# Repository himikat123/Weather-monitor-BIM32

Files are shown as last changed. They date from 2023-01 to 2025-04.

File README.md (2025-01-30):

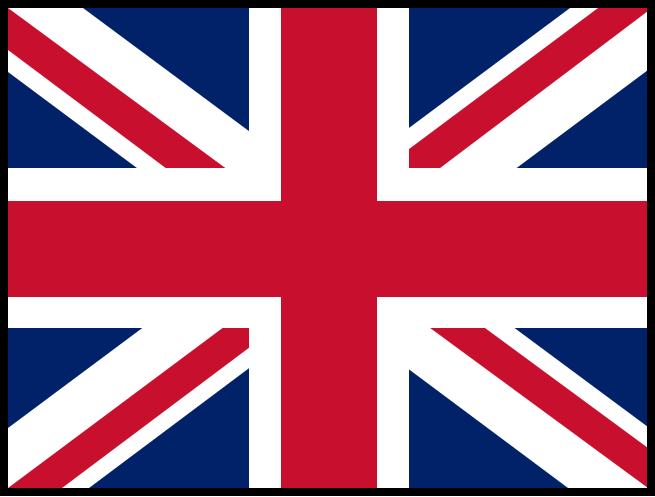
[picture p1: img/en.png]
Read this in english

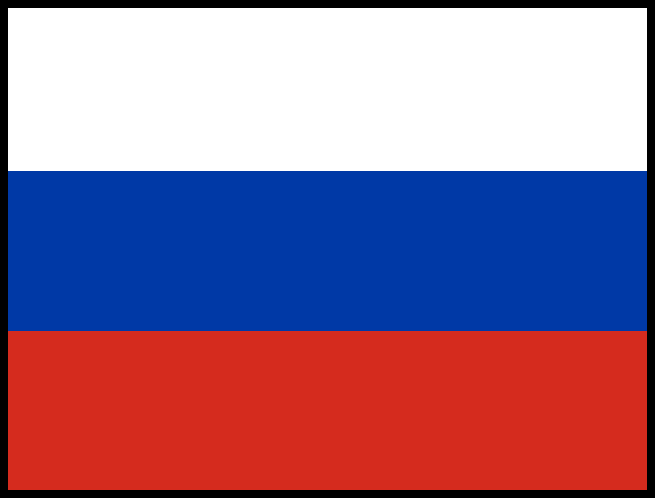
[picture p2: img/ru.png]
Читать на русском


# BIM32 weather monitor
## Weather monitor on ESP32

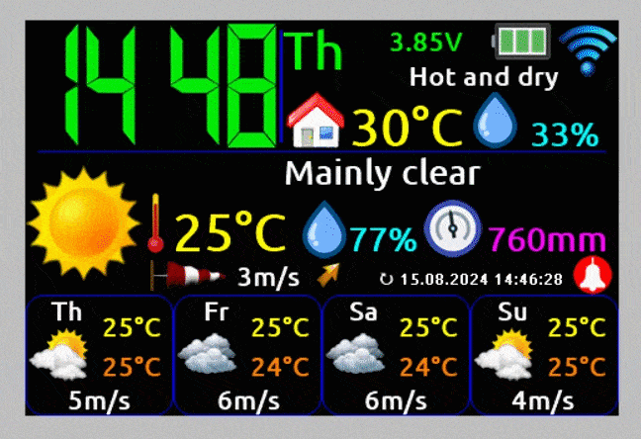
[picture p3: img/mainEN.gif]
Weather monitor based on ESP32


### Brief list of weather monitor features:

* Connect to home WiFi network 2.4 GHz
* Display current weather and weather forecast for 3 days
* Display hourly weather forecast for 5 days
* Display weather history (hourly) for 1 day ago
* Charts building (temperature, humidity, pressure and precipitation probability)
* Display Temperature, Humidity, CO2 and Index of Air Quality in the house
* Home weather control (Humidifier, Dehumidifier, Heater, Cooler and Purifier)
* Clock (Small/Large/With seconds/Analog) with NTP synchronization
* Calendar with the ability to scroll up to plus/minus infinity
* Sending and/or receiving data from/to thingspeak
* Sending data to narodmon
* Up to 2 wireless Temperature/Pressure/Humidity/CO2/ambient light/voltage/current/power/energy sensors
* Support wired Temperature/Pressure/Humidity/Index of Air Quality/Ambient light sensors
* Auto-adjust the brightness of the screen backlight (by ambient light sensor, by time or by the fact of sunrise and sunset)
* 3.5 or 3.2 inch color touch display
* Support 6 languages: English, German, Russian, Polish, Ukrainian, Bulgarian
* Optional 7-segment color display of large and even huge clocks
* Talking clock
* Alarm clock playing mp3 files
* Sound alert when Temperature, Humidity, CO2 and Air Quality go beyond comfort limits
* Very flexible settings via web interface

```diff 
- Attention to all who want to add support for the sensor or display you need. There are three ways to do this:
- 1. Do it yourself, the source code is freely available
- 2. Send me the sensor/display you need
- 3. Pay for adding the sensor/display you need
```

## Wiring diagram for base weather monitor modules
To start and operate the weather monitor, just connect **display** to **ESP32**. Connecting all other modules is optional.

Instead of schematic diagrams, I post half-drawings, half-photos, so that it is clear to beginners and even non-professionals. I ask professionals not to be upset, normal schematic diagrams will also be.

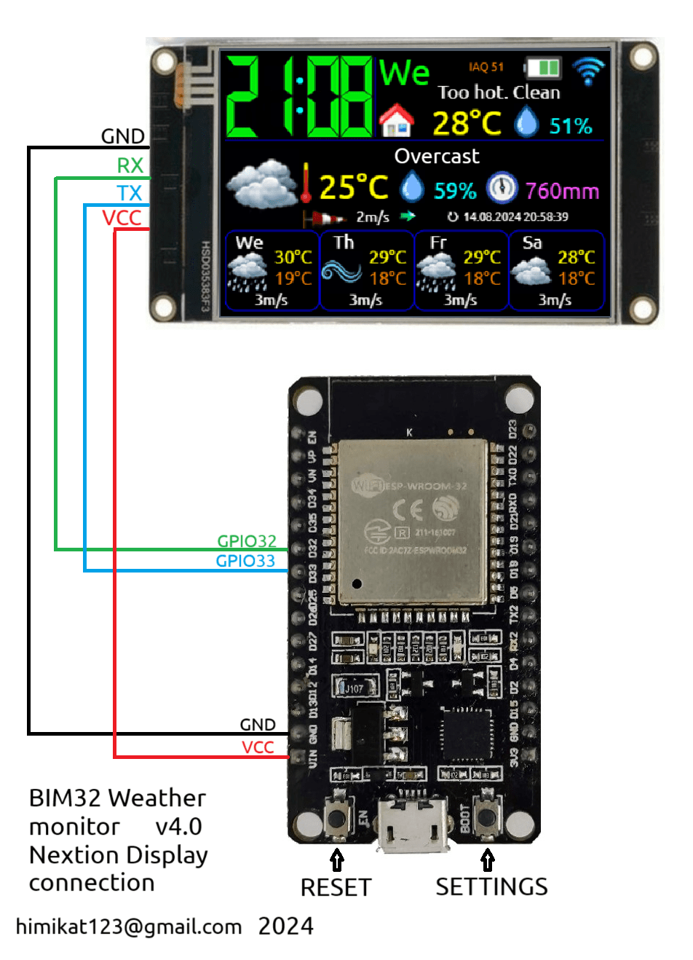
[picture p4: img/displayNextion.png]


You can use the extended version of the **Nextion** display **NX4832K035**, or the basic **NX4832T035**. In the case of the basic model, you will not have access to the clock with seconds, weather graphs, and alarm control from the screen.

Alternatively, you can use the ILI9341 display.

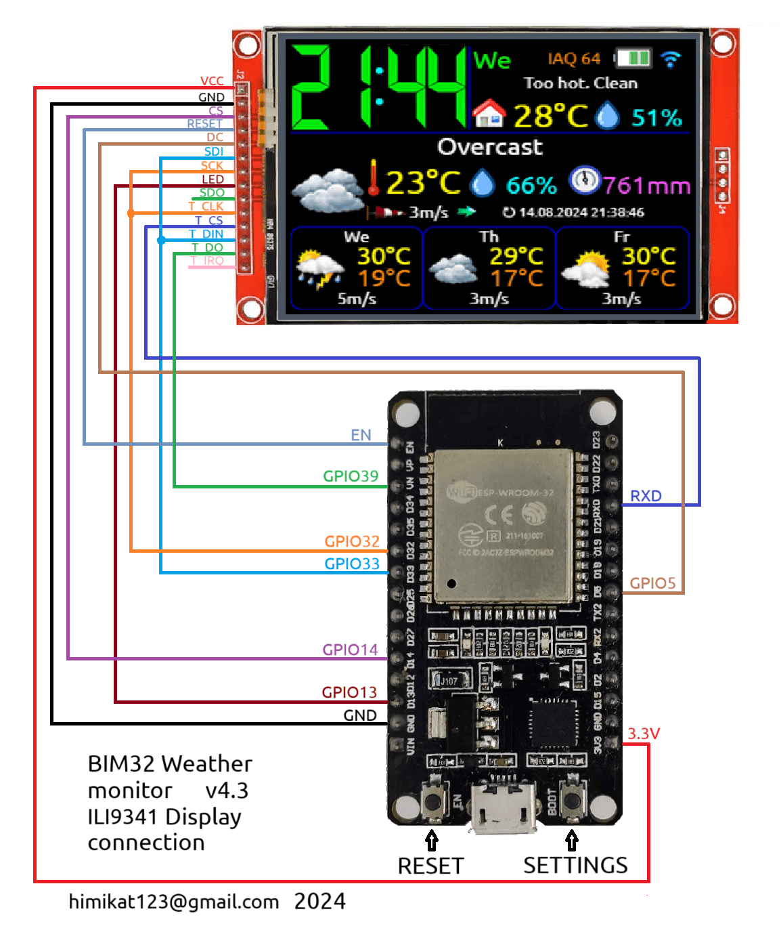
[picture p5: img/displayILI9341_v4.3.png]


If anyone need to have a display on/off button at hand, it can be connected according to the following scheme.

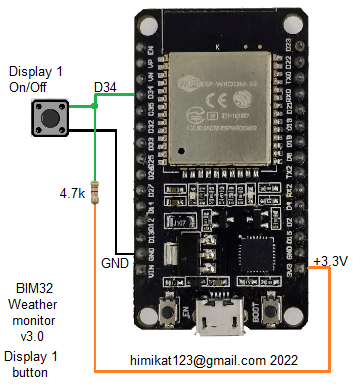
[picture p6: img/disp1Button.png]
weather monitor BIM32 display 1 button


## Wiring diagram of connecting wired sensors to the weather monitor
To the **weather monitor** can be connected wired sensors for temperature, humidity, pressure, index of air quality and ambient light. **The monitor** supports the following sensors:
* BME280
* BME680
* BMP180
* SHT21
* DHT22
* DS18B20
* MAX44009
* BH1750
* photoresistor

You can connect any one, several, or all sensors from this list at once. If your display is not **NX4832K035** it is recommended to install the DS3231 real time clock chip. The connection diagram is as follows.

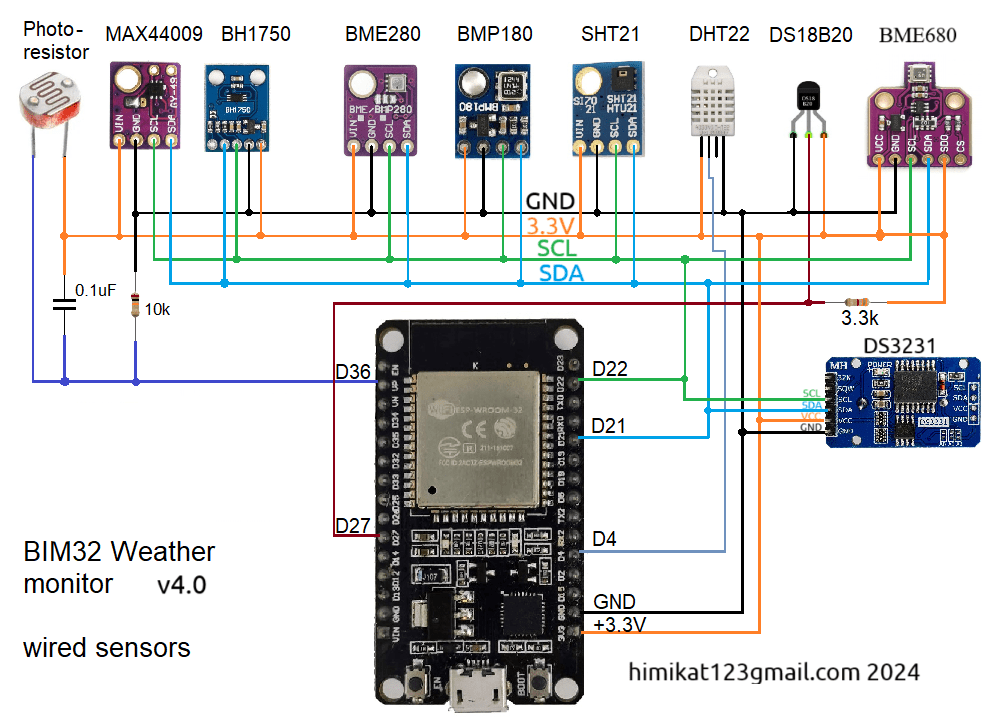
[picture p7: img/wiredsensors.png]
weather monitor BIM32 wired sensors


## Wiring diagram of the radio channel module for communication with wireless sensors
Also, **[wireless sensors](https://github.com/himikat123/Radio-sensor)** can be connected to the **weather monitor**, for this you need to add the radio channel module **HC-12** according to the diagram below.

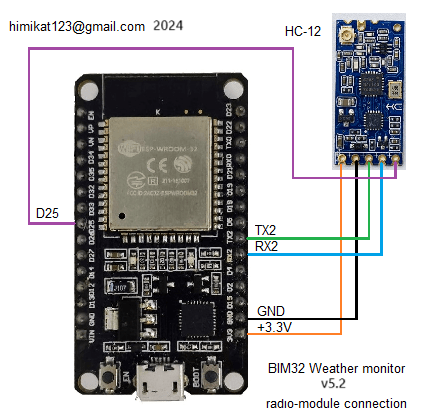
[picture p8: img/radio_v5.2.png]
weather monitor BIM32 radio channel


## Wiring diagram for weather control devices in the house
To control the weather in the house, you can connect a humidifier and dehumidifier, as well as a heater, cooler (fan or air conditioner) and air purifier. I cannot provide a connection diagram for these devices, since everything depends on how the control is implemented in each specific device (remote control, buttons, voltage). Therefore, I will simply indicate on which pins of **PCF8574** logical signals will appear when need to turn on this or that device.

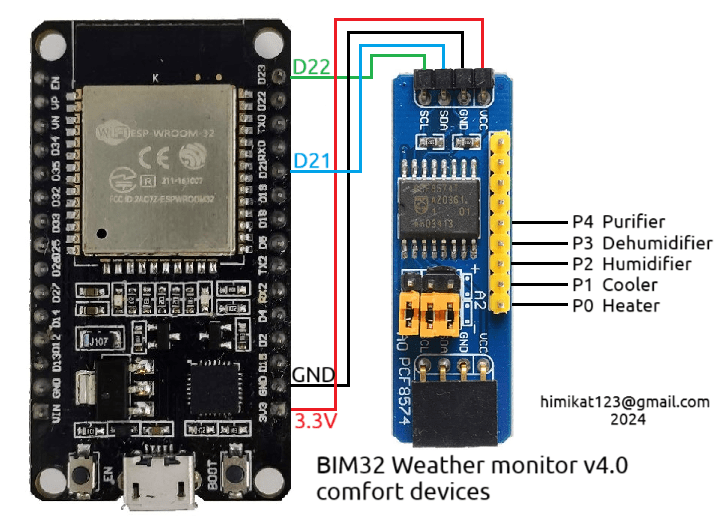
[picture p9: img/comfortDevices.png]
weather monitor BIM32 humidifier dehumidifier heater cooler


## Sound module connection diagram
To enable the alarm clock and the talking clock to produce sounds, the **DF-Player mini** mp3 player module is used, the connection diagram for which is shown below. You will need to copy the entire contents of the **SDcard** folder to the **micro-sd card**, having previously formatted it in the FAT32 file system. If you do not need sound, just connect the GPIO18 ESP32 pin to ground.

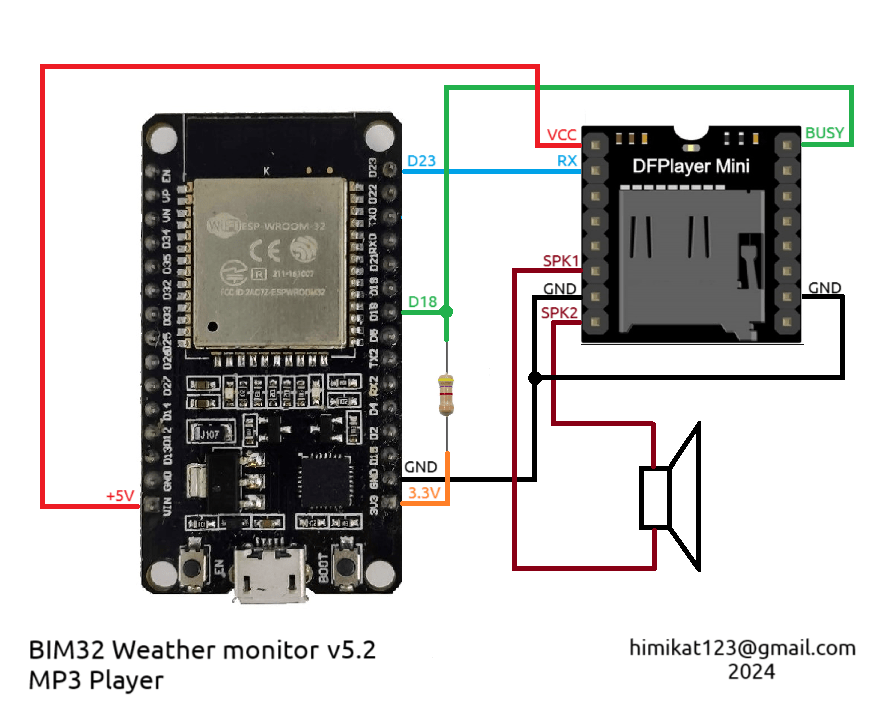
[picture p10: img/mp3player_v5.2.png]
weather monitor BIM32 MP3-player


Having used this device, an unpleasant moment was discovered: this mp3 player module produces a constant low noise. To get rid of the noise, you need to re-solder the resistor from position A to position B, shown in the photo below. This manipulation switches the MUTE input of the amplifier to the BUSY output, on which a log. signal appears only during sound playback.

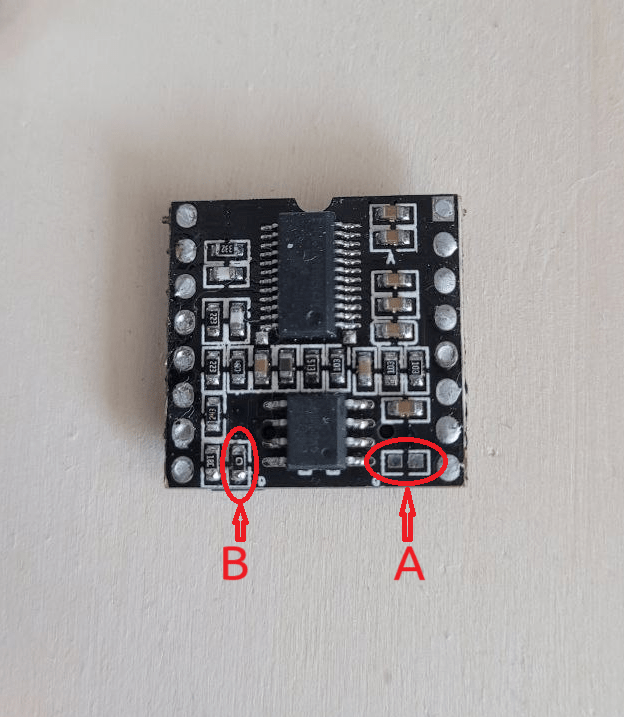
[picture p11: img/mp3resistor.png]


## Weather monitor circuit

Well, as promised, a normal general schematic diagramm for general development. 

```diff 
- Please note if you choose not to install buttons 
- (turn on/off displays and turn off alarms), 
- the pull-up resistors of these buttons still need to be installed.
```

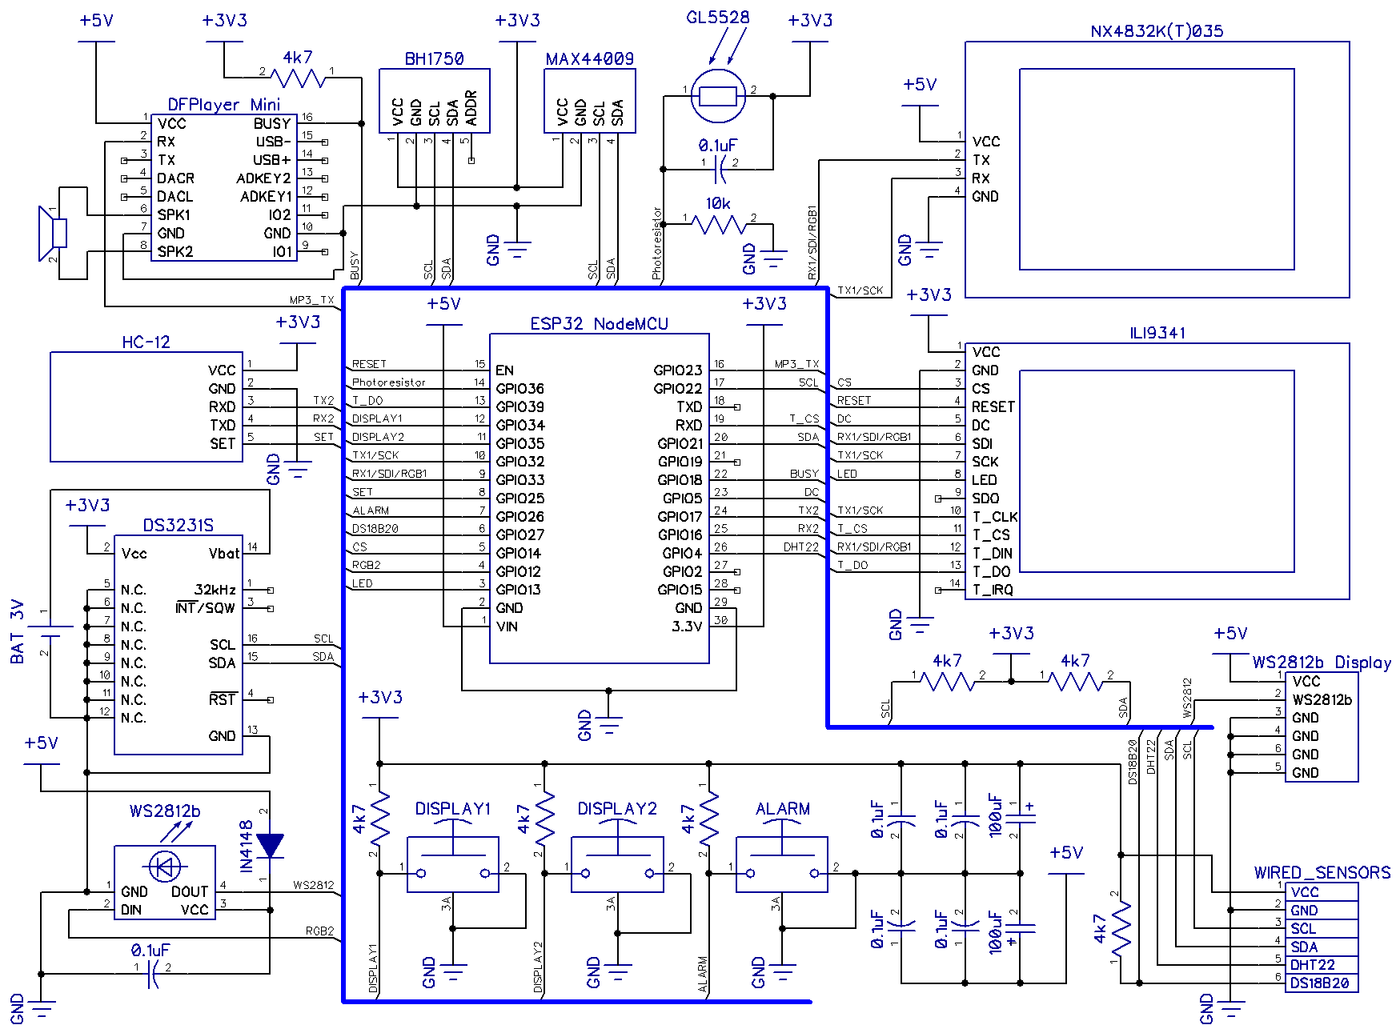
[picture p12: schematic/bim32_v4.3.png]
weather monitor BIM32 schematic diagramm


## Weather monitor flashing
To flash the weather monitor, you will need a **micro-sd** card, a **micro-USB** cable and a computer.

To flash the **Nextion display**, you need to copy the display firmware file (a file with the model name of your display .tft) from the **bin** folder to the **micro-sd** card (the card must be formatted in the **FAT32** file system). Then insert the flash drive into the **micro-sd** slot of the display and supply it with power. The display will flash itself from the flash drive, the flashing progress will be displayed on the screen.

To flash **ESP32**:
1. Download [flash_download_tools](https://www.google.ru/search?q=flash_download_tools)
2. Run it, select ESP32 DownloadTool
3. Select the firmware binaries (located in the bin folder) and the addresses as in the screenshot. And the COM port number
4. Press the Start button in the flashing program and the Settings button on the device (the BOOT button on the ESP32 module). Keep the Settings button pressed until the flashing process starts.

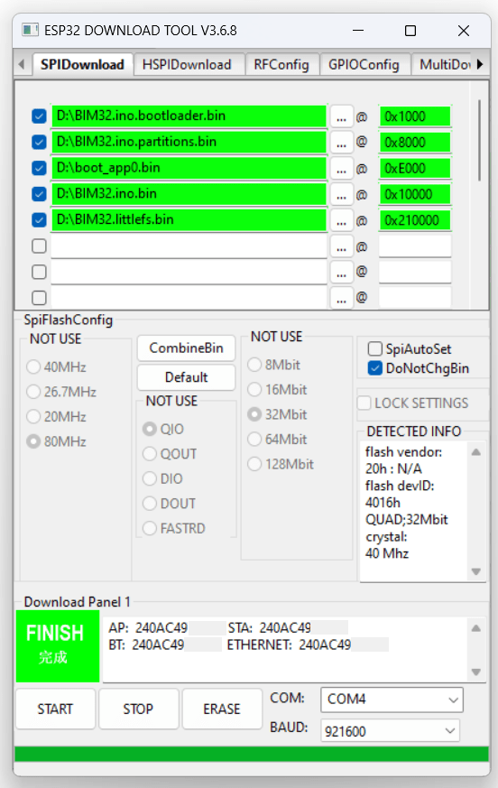
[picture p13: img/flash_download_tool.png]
weather monitor BIM32 flashing


After the flashing **the weather monitor** needs to be configured. An unconfigured device turns on the access point (creates a WiFi network) **BIM32** with the default network password **1234567890**. And in the future, to turn it on again, you need to press and hold the **Settings** button until the access point symbol appears on the screen instead of the antenna symbol. After connecting a laptop or smartphone to the **BIM32** network, open a browser and navigate to **http://192.168.4.1**. Enter login **admin** and password **1111** to open the settings page. In the future, for security reasons, it is recommended to change the default login and password.

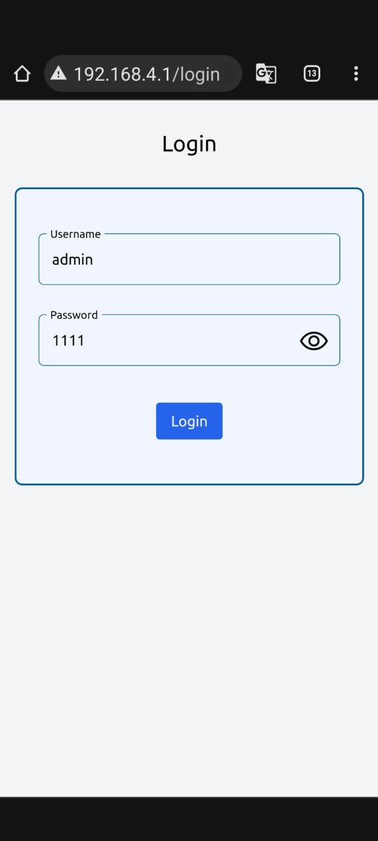
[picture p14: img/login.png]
weather monitor BIM32 login


Also, when the device is already configured and connected to the network, you can get into the settings without pressing the **Settings** button, just enter the IP address of the **weather monitor** in the browser. You can find out this address by tapping on the antenna symbol on the screen of the **weather monitor**.

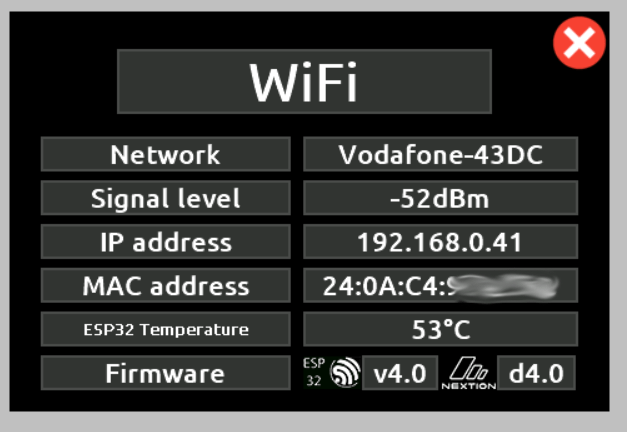
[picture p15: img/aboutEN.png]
weather monitor BIM32 about
<hr />

## A demo of the settings page can be viewed <a href="https://himikat123.github.io/Web-Interface-BIM/" target="_blank">here</a>

## Photos of the weather monitor
Well, and finally traditionally a few photos of the resulting device. The case is printed on a 3D printer, you will find the files for 3D printing in the **enclosure/STL/** folder.

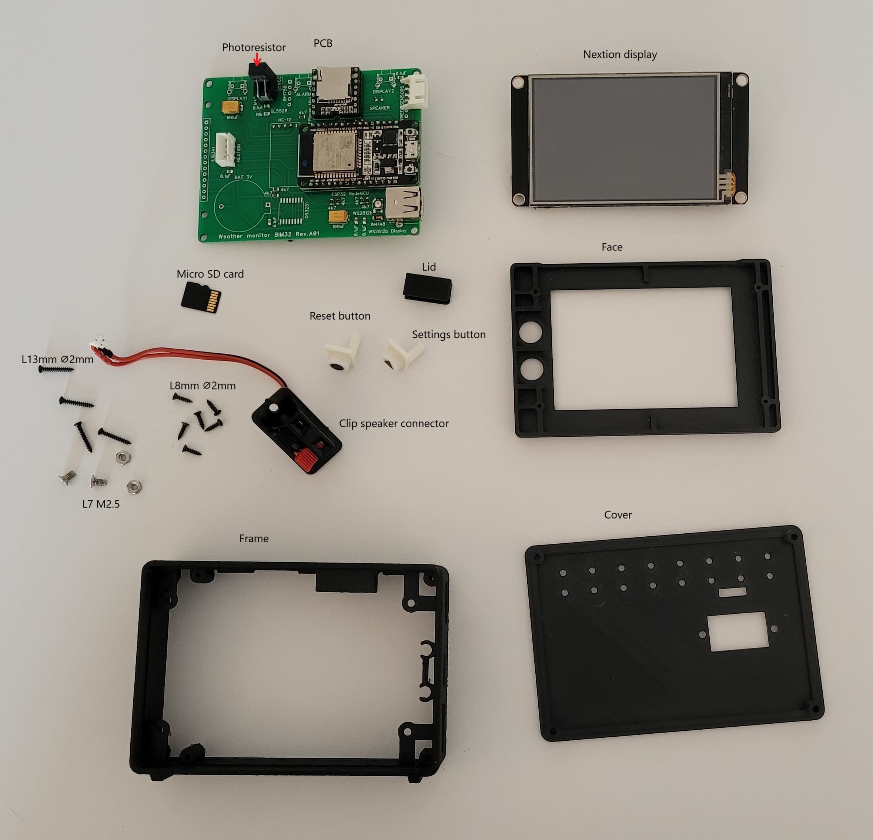
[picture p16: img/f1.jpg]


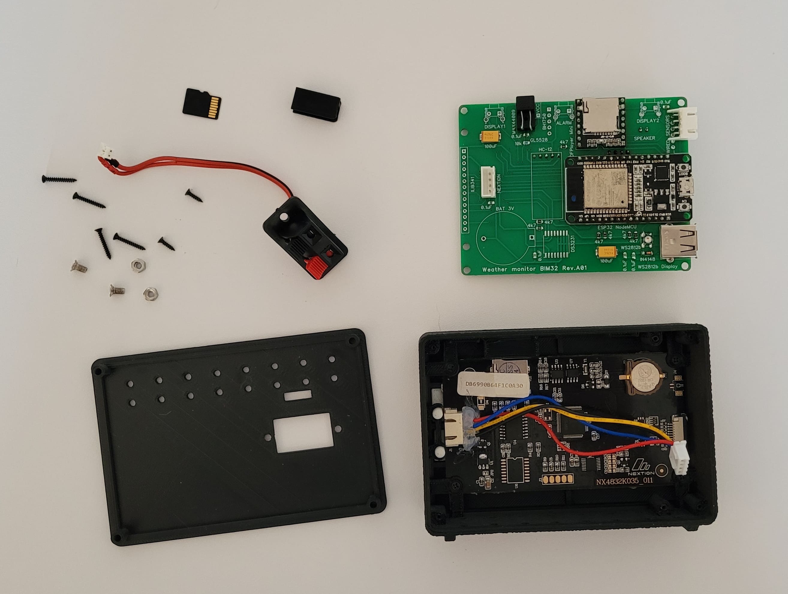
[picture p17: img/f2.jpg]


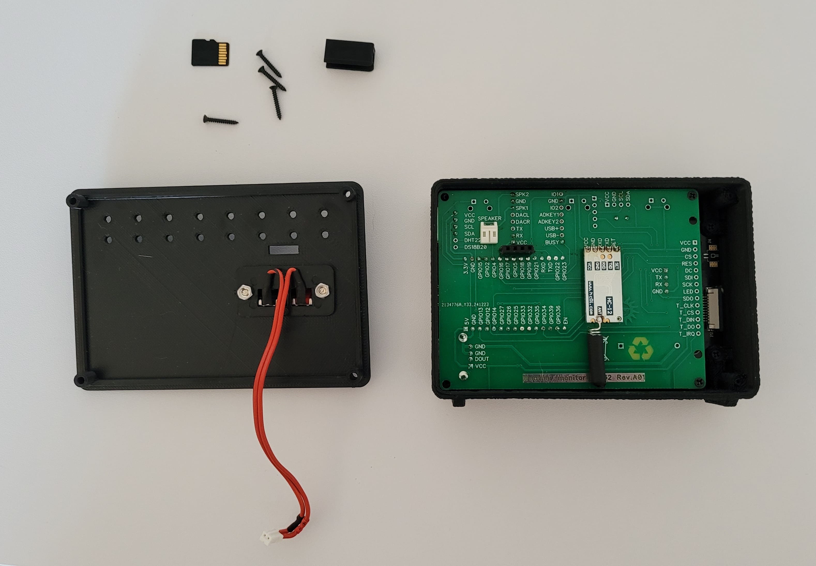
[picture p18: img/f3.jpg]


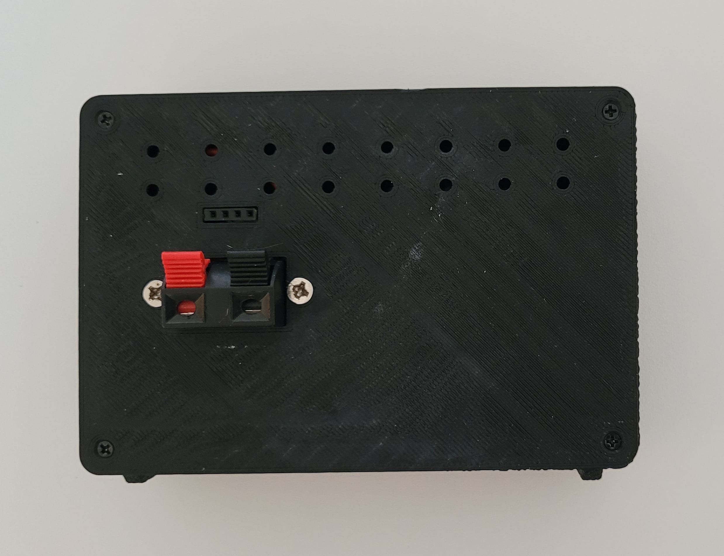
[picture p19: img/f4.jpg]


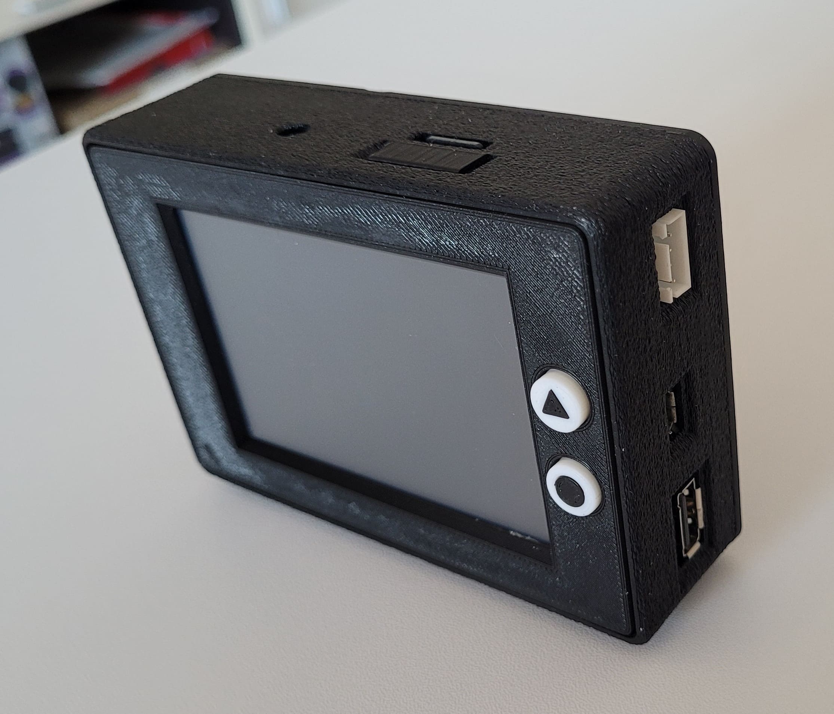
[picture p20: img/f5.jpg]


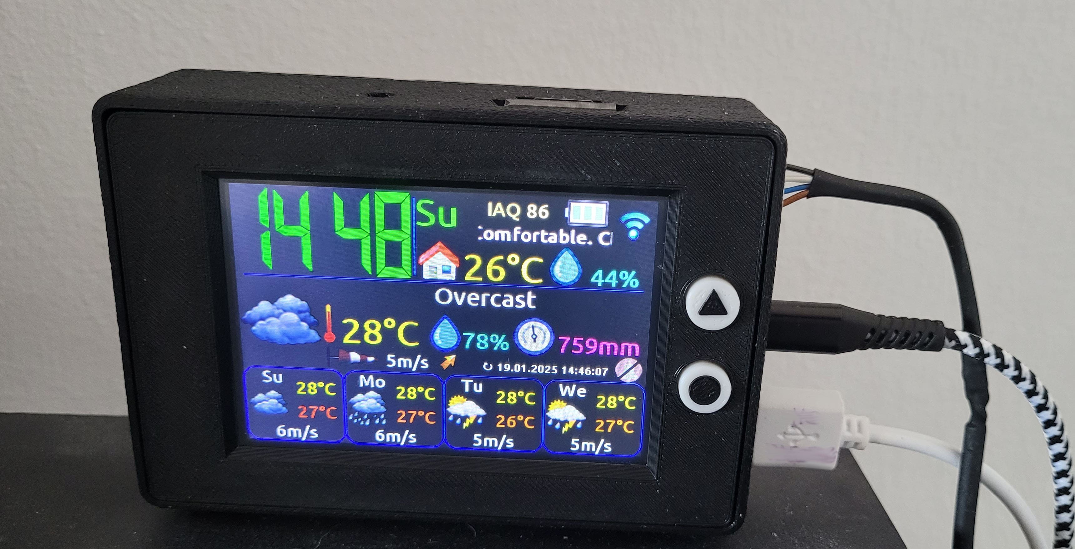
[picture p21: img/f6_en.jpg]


<hr>

## Do you like the project? Buy me coffee or beer.

<a href="https://www.buymeacoffee.com/himikat123Q">
    Donate
</a>

<a href="https://www.paypal.com/donate/?hosted_button_id=R4QDCRKTC9QA6">
    
</a>

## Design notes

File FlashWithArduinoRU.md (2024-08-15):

1. Добавляем в **Arduino IDE** поддержку **ESP32**, находим [инструкцию](https://www.google.ru/search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)
2. Добавляем в **Ардуино** плагин для заливки **SPIFFS** находим [инструкцию](https://www.google.ru/search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)
3. Распаковываем библиотеки из файла **libraries.zip** в папку `C:/Users/Username/Documents/Arduino/libraries`
4. Открываем файл `C:/Users/Username/AppData/Local/Arduino15/packages/esp32/hardware/esp32/1.0.5/platform.txt` и находим (поиском) строчку
`compiler.elf2hex.extra_flags=`, добавьте новую строку: `compiler.libraries.ldflags=`

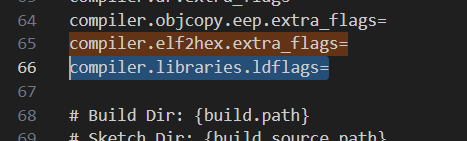
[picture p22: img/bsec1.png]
BSEC flags


Потом, в этом же файле, находим `{compiler.c.elf.libs}` и добавляем за ним, в ту же строку: `{compiler.libraries.ldflags}`

BSEC ldflags

5. Прошиваем плату скетчем
6. Прошиваем файлы файловой системы **SPIFFS**, в Ардуино нужно выбрать **Инструмены --> ESP32 Sketch Data Upload**

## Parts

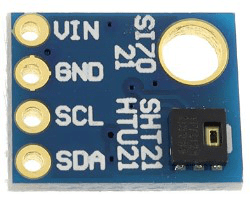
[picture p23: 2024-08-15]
img/components/sht21.png

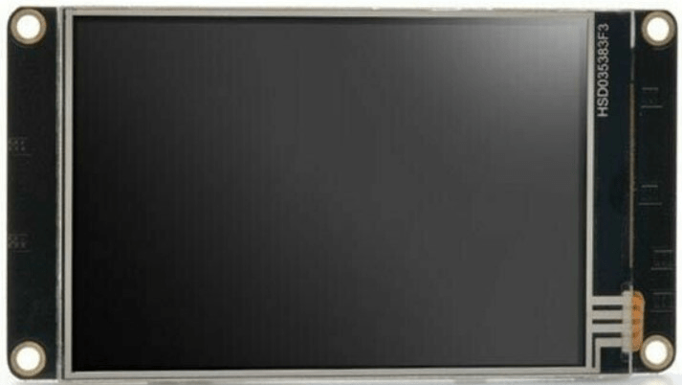
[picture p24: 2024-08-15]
img/components/nextion.png

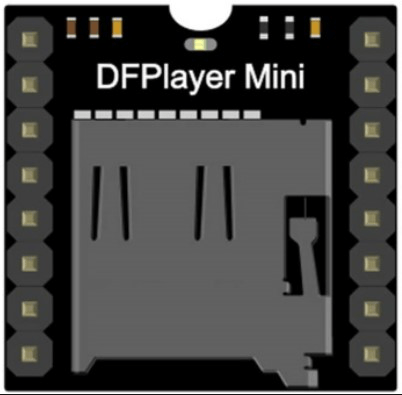
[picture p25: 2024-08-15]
img/components/df-player mini.png

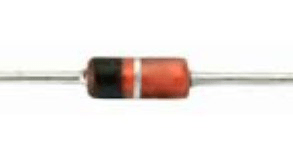
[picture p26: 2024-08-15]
img/components/1n4148.png

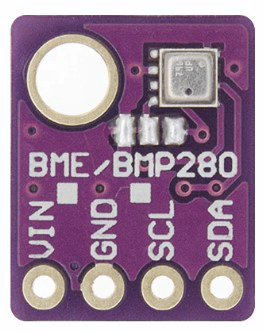
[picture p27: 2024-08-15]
img/components/bme280.png

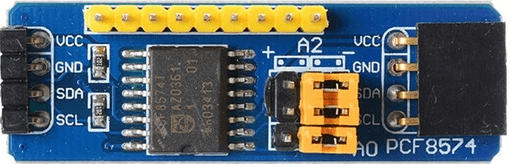
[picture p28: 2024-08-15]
img/components/pcf8574.png

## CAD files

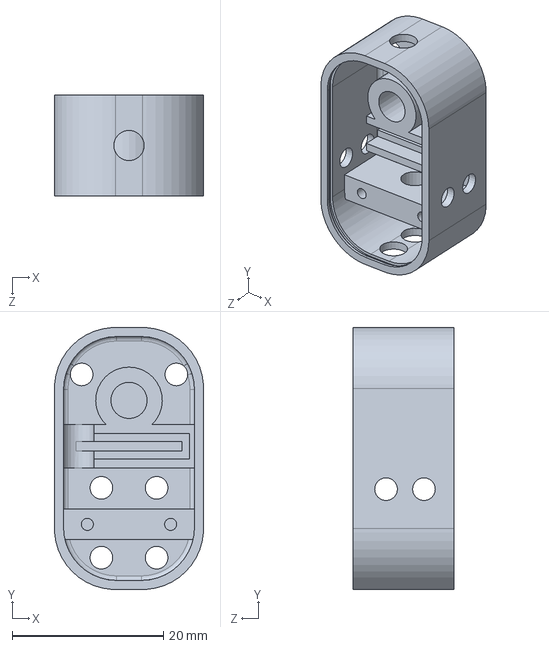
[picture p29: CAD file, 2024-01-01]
enclosure/BME680 enclosure/SOLIDWORKS 2023/BME680_main.SLDPRT
19.7 x 34.6 x 13.4 mm

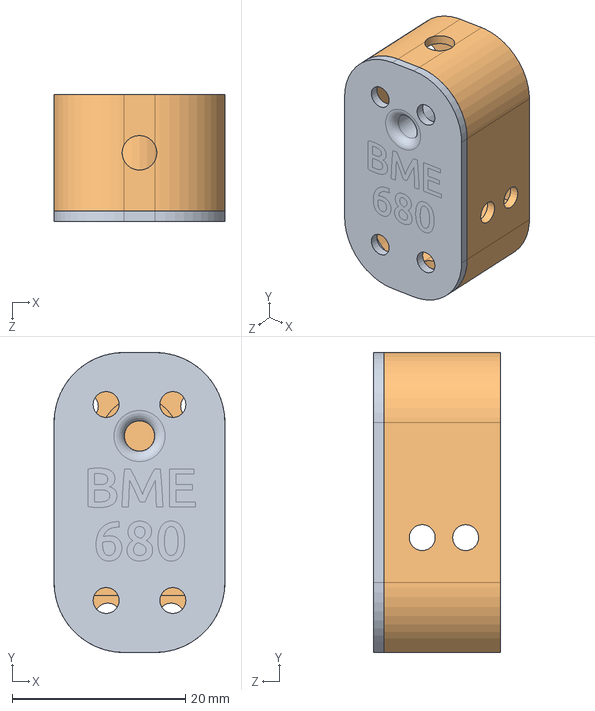
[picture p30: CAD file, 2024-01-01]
enclosure/BME680 enclosure/SOLIDWORKS 2023/BME680_assembly.SLDASM
19.7 x 34.6 x 14.6 mm
BME680_main
BME680_cover

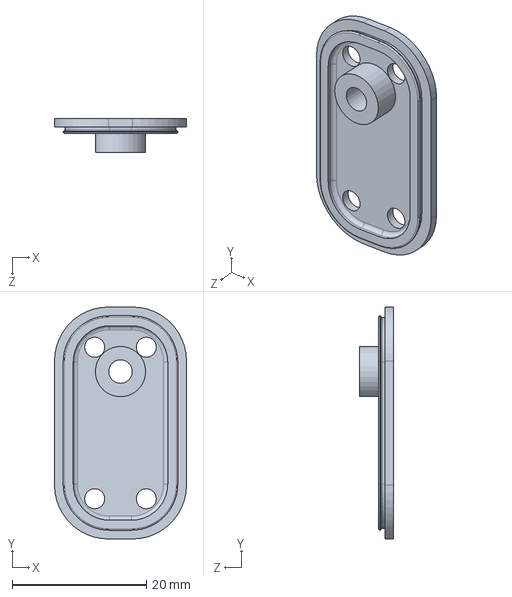
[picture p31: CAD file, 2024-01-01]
enclosure/BME680 enclosure/SOLIDWORKS 2023/BME680_cover.SLDPRT
19.7 x 34.6 x 5.00 mm

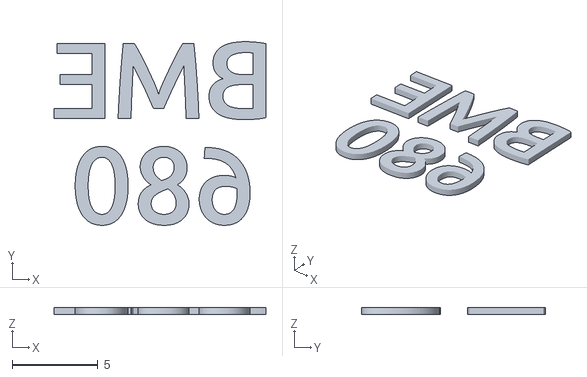
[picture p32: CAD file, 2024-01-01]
enclosure/BME680 enclosure/STL/cover for 2 color print/BME680_cover_black.STL
12.4 x 10.7 x 0.4

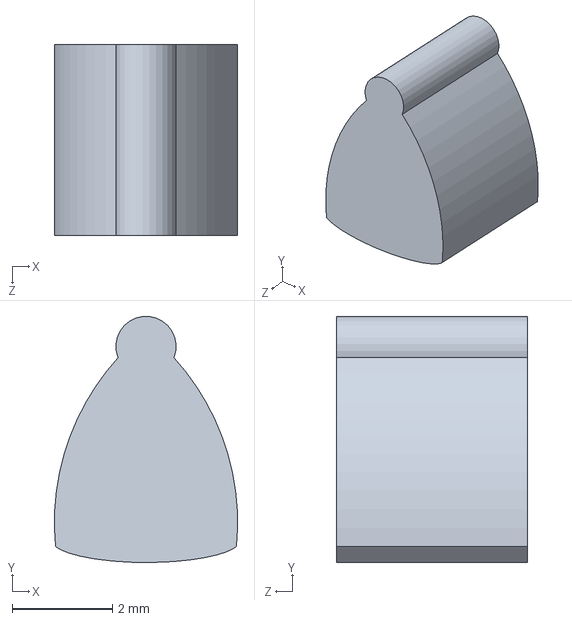
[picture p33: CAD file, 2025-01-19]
enclosure/Solidworks2023/buttons/alarm/alarm_black.SLDPRT
3.65 x 4.90 x 3.80 mm

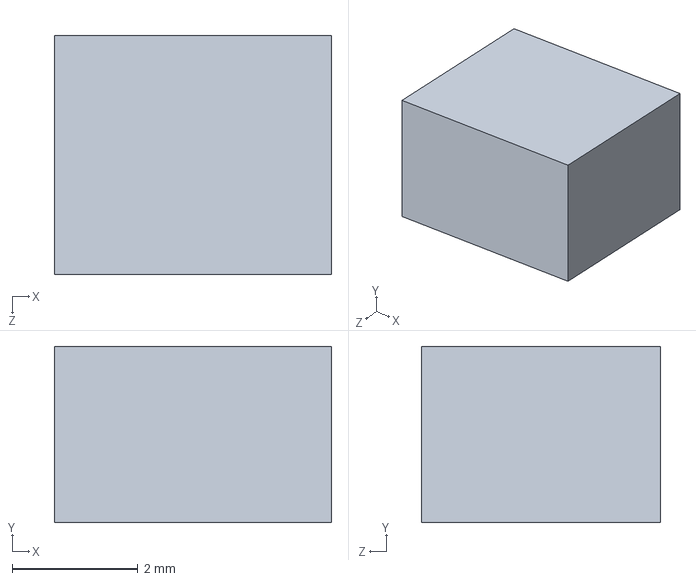
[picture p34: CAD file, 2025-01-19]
enclosure/Solidworks2023/buttons/display_1/disp1_black.SLDPRT
4.40 x 2.80 x 3.80 mm

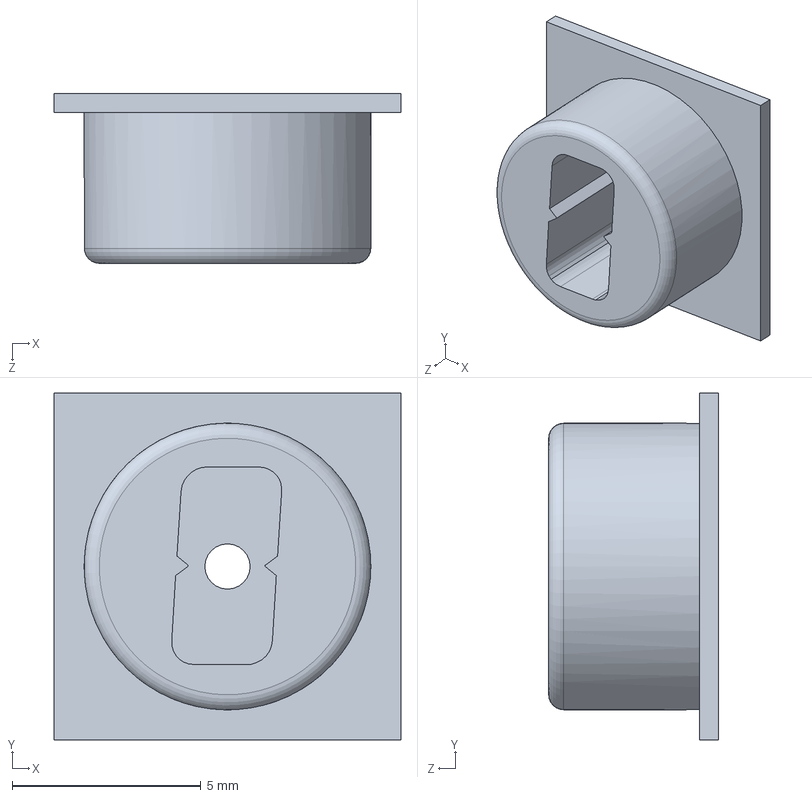
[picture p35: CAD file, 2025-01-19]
enclosure/Solidworks2023/buttons/display_2/disp2_white.SLDPRT
9.20 x 9.20 x 4.50 mm

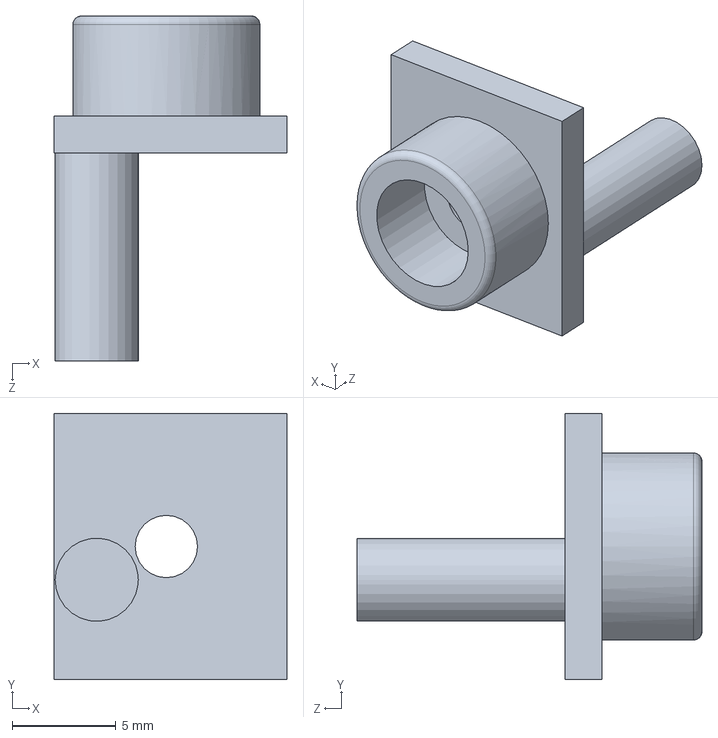
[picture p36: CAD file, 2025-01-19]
enclosure/Solidworks2023/buttons/reset/reset_white.SLDPRT
11.2 x 12.8 x 16.6 mm

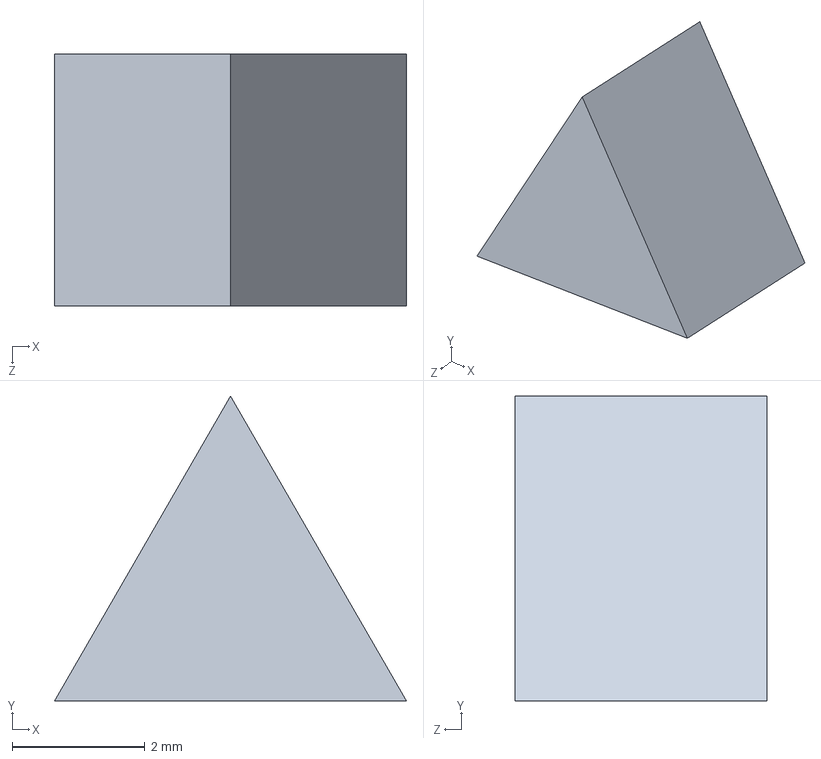
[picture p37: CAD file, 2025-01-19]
enclosure/Solidworks2023/buttons/settings/setiings_black.SLDPRT
5.31 x 4.60 x 3.80 mm

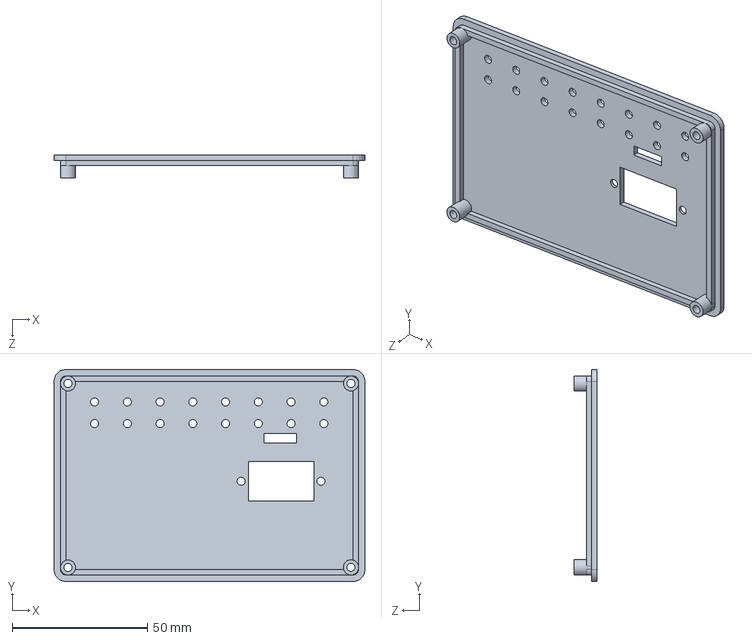
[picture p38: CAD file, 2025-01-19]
enclosure/Solidworks2023/cover/cover.SLDPRT
114.9 x 78.4 x 8.60 mm

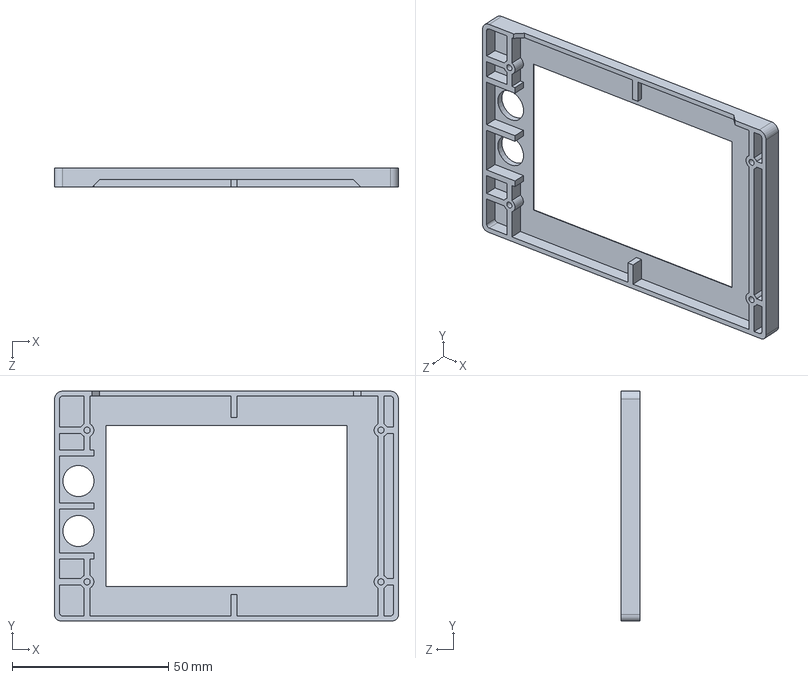
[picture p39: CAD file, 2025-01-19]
enclosure/Solidworks2023/face/face.SLDPRT
110.1 x 73.6 x 6.20 mm

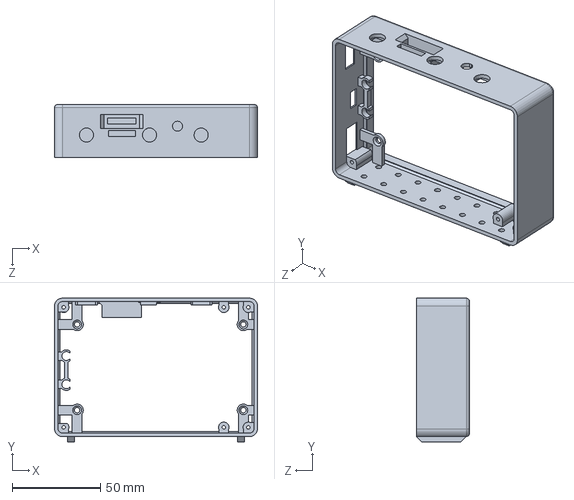
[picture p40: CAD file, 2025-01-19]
enclosure/Solidworks2023/frame/frame.SLDPRT
114.9 x 81.4 x 30.0 mm

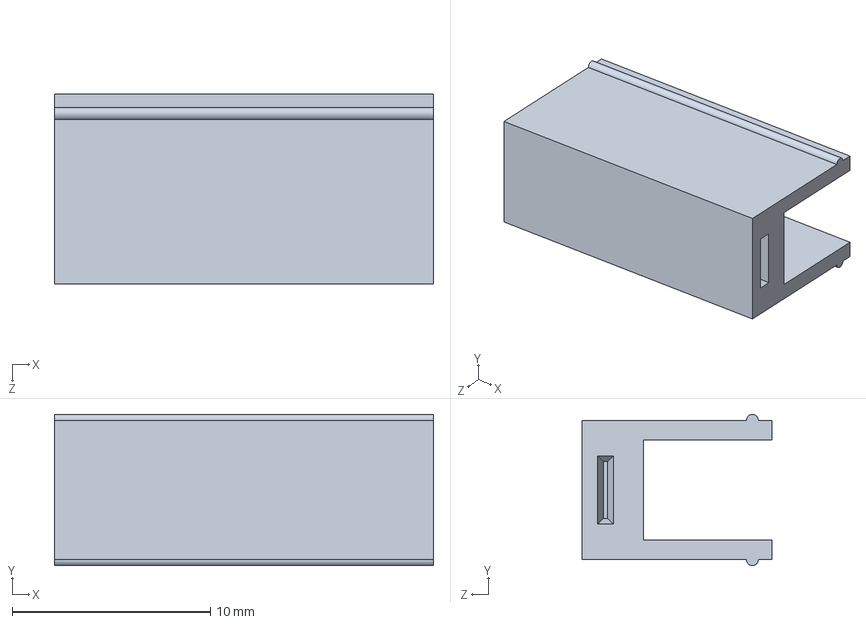
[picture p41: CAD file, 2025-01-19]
enclosure/Solidworks2023/lid/lid.SLDPRT
19.1 x 7.63 x 9.60 mm

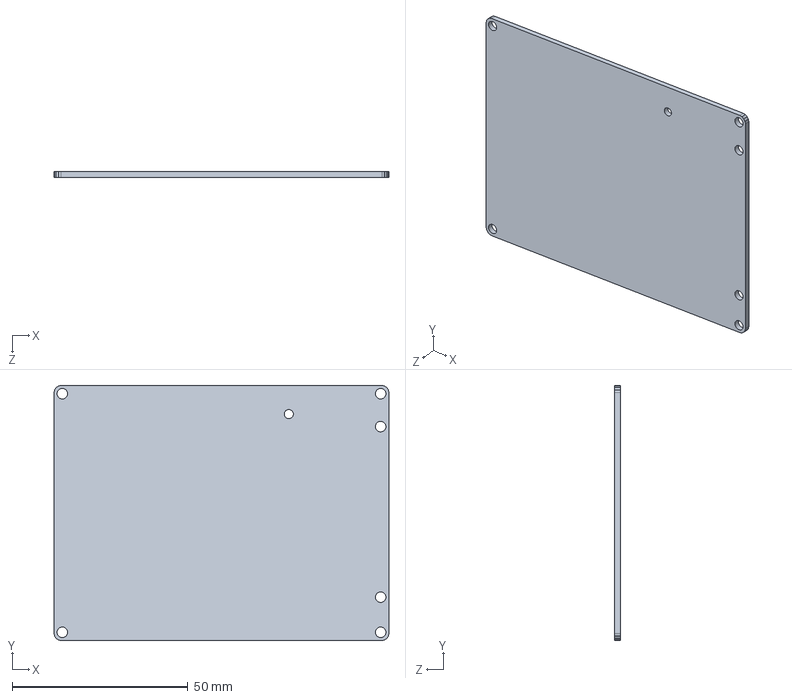
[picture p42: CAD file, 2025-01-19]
enclosure/Solidworks2023/pcb/board.SLDPRT
95.4 x 72.7 x 1.60 mm

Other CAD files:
enclosure/BME680 enclosure/STL/BME680_main.STL
enclosure/BME680 enclosure/STL/BME680_cover.STL
enclosure/Solidworks2023/photoresistor/photoresistor.SLDPRT
enclosure/STL/buttons/alarm/alarm_black.STL
PCB/diptrace/3d models/BH-642_Battery_holder.STEP
PCB/diptrace/3d models/HC-12.STEP
PCB/diptrace/3d models/ILI9341_3_2.step
PCB/diptrace/3d models/JST - XH - Thru (R) - 2Pin - 2.54mm.stp
PCB/diptrace/3d models/JST - XH - Thru (R) - 6Pin - 2.54mm.stp
PCB/diptrace/3d models/JST - XH - Thru (V) - 4Pin - 2.54mm.stp
PCB/diptrace/3d models/USB Connector Type A female.STEP
PCB/diptrace/3d models/WS2812B.step
PCB/diptrace/3d models/bh1750_90deg.STEP
PCB/diptrace/3d models/button.step
PCB/diptrace/3d models/esp32.STEP
PCB/diptrace/3d models/gl5528.STEP
PCB/diptrace/3d models/max44009.STEP
enclosure/BME680 enclosure/SOLIDWORKS 2023/CJMCU-680.SLDPRT
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

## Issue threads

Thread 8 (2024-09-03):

Problems with DFPlayer.

micko-24, 2024-09-03:
DFplayer in version 4.0-4.2 does not work well. It keeps turning off when you click on the melody, and when it works, it turns on at any time, regardless of whether it is turned off in the settings. The LCD sometimes goes to sleep for no reason (v4.0 -4.20).In older versions, DFplayer works normally without errors.

himikat123, 2024-09-05:
Thank you, I'm trying to reproduce your problems, but everything works with any of my settings. Maybe you can send me your config file (without passwords of course)

micko-24, 2024-09-06:
[config.json](https://github.com/user-attachments/files/16912258/config.json)

himikat123, 2024-09-11:
Try the new firmware, everything seems to be fixed. Note that the dfplayer connection diagram has been changed.
It turned out that the player works unstably if there are debug data at the uart input so I had to connect it to another output, as it was before. And the esp32 gpio36 input has a hardware error, interrupts do not work correctly on it, so I will now use gpio18 instead

micko-24, 2024-09-11:
Thank you, now everything works stably. Can you help me make a 3D box for the version of the BIM weather monitor ESP8266 (I had it made, and the manufacturer gave me this message - Please note that there are more than one shell and they cannot be unified automatically. Sorry to tell you that each file can only support 1 shell. Could you please unify the parts into one unit? Or how about separating the several shells into several files to proceed the orders separately , we will activate the 'replace file' button for you.

himikat123, 2024-09-11:
Perhaps you sent him all the 3d box files at once. But there is a separate folder for each part, where there is a file for printing in one color and a folder with files for printing in two colors. You just need to decide whether you are printing in one color or two and delete unnecessary files

micko-24, 2024-09-11:
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

micko-24, 2024-09-12:
Dear Sir,
I sent another order for 3d printing and got this reply.

But truly sorry that the issues are still existing as follows:

1,the wall thickness of those indicated red area is too thin, which has high risks of loss, deformation ,crack, or damage during the printing process.

Could you please confirm if the risks are acceptable for you?

If not, could you please kindly increase it to be at least 0.8 mm to proceed? 1.5 mm will be better .Then we will activate the ' replace file' button for you.

2,kindly please note that there are more than one shell and they can not be unified automatically. Sorry to tell you that each file can only support 1 shell (1 model) print.Could you please unify the parts and combine them into one unit?  Or how about separating the several shells into several files to proceed the orders separately.To save time,we will activate the 'replace file' button for you.
Can you help me with this problem.(BIM weather monitor ESP8266)
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

Thanks.

himikat123, 2024-09-12:
Hi, please answer me the questions, will you print in one color or two? Who do you order 3D printing from?

micko-24, 2024-09-12:
I will work in one color. I am ordering from
JLCPCB.I did the first versions of bim32 and everything was fine.

himikat123, 2024-09-12:
try this files
[STL.zip](https://github.com/user-attachments/files/16982638/STL.zip)

micko-24, 2024-09-13:
Dear Sir,
all files are ok, except reset_btn.stl and settings_btn.stl. The manufacturer reports this error.
Order Reviewed: 2024-09-13 04:22:36
Audit failure reason:

Multiple parts are detected in your file, sorry to tell you that each file could only support 1 part for printing, if all the separated parts intended to be integrated, please kindly unify all the separate parts in one to proceed. Thanks!

Can it be corrected or simply fill in the places where the buttons are located (face.stl).
Thanks.

micko-24, 2024-09-13:
Dear Sir,
can you edit this file for me so that it doesn't have keyholes.
Thanks.
[face.zip](https://github.com/user-attachments/files/16997423/face.zip)

micko-24, 2024-09-13:
I need this version number 2.

micko-24, 2024-09-13:
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

himikat123, 2024-09-13:
ah, i misunderstood, here it is
[face2.zip](https://github.com/user-attachments/files/16998123/face2.zip)

micko-24, 2024-09-15:
Dear Sir,
I just received an email from the manufacturer asking for the wall thickness marked in red in the picture to be increased to at least 0.8mm, and the recommended 1.5mm.
Thanks.
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
[face2.zip](https://github.com/user-attachments/files/17004990/face2.zip)

himikat123, 2024-09-15:
Hi micko-24

what a strict manufacturer :)

Here is a new file
[face3.zip](https://github.com/user-attachments/files/17005070/face3.zip)

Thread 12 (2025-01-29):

Добавить поддержку CYD

Morozheno, 2025-01-29:
Есть популярный экран [ESP32 Cheap Yellow Display (CYD)](https://randomnerdtutorials.com/esp32-cheap-yellow-display-cyd-pinout-esp32-2432s028r/) (ESP32-2432S028) с тачем sd картой кучей корпусов на tingiverse звуком несколькими дополнительными io rgb светодиодом и датчиком освещения
[Ссылка на али](https://aliexpress.ru/item/1005006308949167.html) (конкретно этот на st7789)
нет ли возможности хотябы базово добавить поддержку этого экрана в проект ?

Closed 2025-02-01.

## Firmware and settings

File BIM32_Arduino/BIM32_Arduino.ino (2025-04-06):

/**
 *  Weather Monitor BIM32 v5.5
 *  https://github.com/himikat123/Weather-monitor-BIM32
 *
 *  © himikat123@gmail.com, Nürnberg, Deutschland, 2020-2025
 *
 *  Board: ESP32 Dev Module
 *  Partition sheme: No OTA (2MB APP/2MB SPIFFS)
 *
 *  Arduino IDE v1.8.19
 *  ESP32 board by Espressif Systems v2.0.14
 */


/* Arduino libraries */
#include <Arduino.h>
#include <ArduinoOTA.h>
#include "FS.h"
#include <LittleFS.h>
#include <Update.h>
#include <WiFi.h>
#include <HTTPClient.h>
WiFiClient client;
#include <WebServer.h>
WebServer server(80);
#include <ESPmDNS.h>
#include <time.h>

/* External Libraries */
#include <ArduinoJson.h> // v7.0.3 https://arduinojson.org/?utm_source=meta&utm_medium=library.properties
#include <TimeLib.h> // v1.6.1 https://playground.arduino.cc/Code/Time/
#include "ESP32SSDP.h" // v1.2.1 https://github.com/luc-github/ESP32SSDP

/* Pictures */
#include "src/picturesAnts.hpp"
#include "src/picturesBats.hpp"
#include "src/picturesIconsBig.hpp"
#include "src/picturesIconsSmall.hpp"
#include "src/picturesIconsTiny.hpp"
#include "src/picturesLogo.hpp"
#include "src/picturesNumbers.hpp"
#include "src/picturesSymbols.hpp"
#include "src/picturesWind.hpp"
#include "src/picturesWindTiny.hpp"

/* Own classes */
#include "src/validate.hpp"
Validate validate;
#include "src/globals.hpp"
Configuration config;
#include "src/sensors.hpp"
Sensors sensors;
#include "src/languages.hpp"
Lang lang;
#include "src/wirelessSensor.hpp"
WirelessSensor wsensor;
#include "src/weather.hpp"
Weather weather;
#include "src/sound.hpp"
Sound sound;
#include "src/agregateSendData.hpp"
AgregateSendData agregateSendData;
#include "src/thingspeak.hpp"
Thingspeak thingspeak;
#include "src/narodmon.hpp"
Narodmon narodmon;
#include "src/mqtt.hpp"
MQTT mqtt;
#include "src/fonts.hpp"
#include "src/agregateLcdData.hpp"
AgregateLcdData agregateLcdData;
#include "src/lcdDisplay.hpp"
#include "src/nextion.hpp"
Nextion nextion;
#include "src/ili9341.hpp"
ILI9341 ili9341;
#include "src/agregateSegmentData.hpp"
AgregateSegmentData agregateSegmentData;
#include "src/segmentAnimationsShifts.hpp"
#include "src/segmentDisplay.hpp"
#include "src/ws2812display.hpp"
WS2812b ws2812b_1;
WS2812b ws2812b_2;
#include "src/softi2c.hpp"
SoftI2C Wire_1 = SoftI2C(PCF8575_1_SDA_PIN, PCF8575_1_SCL_PIN);
SoftI2C Wire_2 = SoftI2C(PCF8575_2_SDA_PIN, PCF8575_2_SCL_PIN);
#include "src/tm1637display.hpp"
TM1637 tm1637_1;
TM1637 tm1637_2;
#include "src/max7219segmentDisplay.hpp"
MAX7219_S max7219_1;
MAX7219_S max7219_2;
#include "src/pcf8575SegmentDisplay.hpp"
PCF8575_S pcf8575_1;
PCF8575_S pcf8575_2;
#include "src/network.hpp"
Network network;
#include "src/agregateComfortData.hpp"
AgregateComfortData agregateComfortData;
#include "src/comfort.hpp"
Comfort comfort;

#include "taskdisplay.hpp"
#include "tasksensors.hpp"
#include "taskserver.hpp"

/**
 * Arduino setup
 */
void setup() {
    pinMode(HC12_SET_PIN, OUTPUT);
    digitalWrite(HC12_SET_PIN, HIGH);
    pinMode(DISPLAY1_BUTTON_PIN, INPUT);
    pinMode(DISPLAY2_BUTTON_PIN, INPUT);
    pinMode(ALARM_BUTTON_PIN, INPUT);
    pinMode(MP3_BUSY_PIN, INPUT);

    Serial.begin(115200, SERIAL_8N1, -1, 1);
    Serial2.begin(9600);
    Serial2.onReceive([]() {
        wsensor.handleReceive();
    });

    Serial.println(SEPARATOR);
    Serial.println(SEPARATOR);
    Serial.printf("*  Weather Monitor BIM32 %s    © himikat123@gmail.com   2020-2025  *\r\n", FW);
    Serial.println(SEPARATOR);
    Serial.println();

    if(!LittleFS.begin()) {
        Serial.println("LittleFS initialisation failed!");
        while(1) yield();
    }
    config.readConfig();

    if(config.display_type(0) == LCD_DISPLAY) {
        if(config.display_model(0) == D_NX4832K035 or config.display_model(0) == D_NX4832T035) {
            Serial1.begin(115200, SERIAL_8N1, NEXTION_RX_PIN, NEXTION_TX_PIN);
            nextion.showLogo();
        }
        if(config.display_model(DISPLAY_1) == D_ILI9341) {
            ili9341.init();
            ili9341.showLogo();
        }
    }

    xTaskCreatePinnedToCore(TaskDisplay1, "TaskDisplay1", 32768, NULL, -1, &task_display1_handle, 1);
    xTaskCreatePinnedToCore(TaskDisplay2, "TaskDisplay2", 8192, NULL, -1, &task_display2_handle, 1);

    WiFi.mode(WIFI_STA);
    xTaskCreatePinnedToCore(TaskSensors, "TaskSensors", 32768, NULL, 1, &task_sensors_handle, 1);
    webInterface_init();
    xTaskCreatePinnedToCore(TaskServer, "TaskServer", 16384, NULL, 1, &task_server_handle, 1);
}

void loop() {

}

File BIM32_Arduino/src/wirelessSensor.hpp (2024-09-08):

class WirelessSensor {
    #define WSENSORS 2

    public:
        void handleReceive();
        void receive();
        bool dataRelevance(uint8_t wsensNum);
        int get_updated(unsigned int num);
        String get_sensorType(unsigned int num, unsigned int sensor);
        String get_lightType(unsigned int num);
        String get_energyType();
        String get_co2Type();
        float get_temperature(unsigned int num, unsigned int sensor, bool corr);
        float get_humidity(unsigned int num, bool corr);
        float get_pressure(unsigned int num, bool corr);
        float get_light(unsigned int num, bool corr);
        float get_voltage(unsigned int num, bool corr);
        float get_current(unsigned int num, bool corr);
        float get_power(unsigned int num, bool corr);
        float get_energy(unsigned int num, bool corr);
        float get_frequency(unsigned int num, bool corr);
        float get_co2(unsigned int num, bool corr);
        int get_batteryAdc(unsigned int num);
        float get_batteryVoltage(unsigned int num);
        int get_batteryLevel(unsigned int num);
        float get_batteryPercentage(unsigned int num);

    private:
        uint16_t receivedIndex = 0;
        char receivedData[1024];
        int _updated[WSENSORS] = {-1, -1};               // Last update timestamp
        float _temperature[WSENSORS][5] = {              // Temperature
            {40400.0, 40400.0, 40400.0, 40400.0, 40400.0}, 
            {40400.0, 40400.0, 40400.0, 40400.0, 40400.0} 
        };
        float _humidity[WSENSORS] = {40400.0, 40400.0};  // Humidity
        float _pressure[WSENSORS] = {40400.0, 40400.0};  // Pressure
        char _sensorType[WSENSORS][20] = {"", ""};       // Temperature, Humidity, Pressure sensor type (name)
        float _light[WSENSORS] = {-1.0, -1.0};           // Ambient light
        char _lightType[WSENSORS][20] = {"", ""};        // Ambient light sensor type (name)
        float _voltage[WSENSORS] = {-1.0, -1.0};         // Voltage
        float _current[WSENSORS] = {-1.0, -1.0};         // Current
        float _power[WSENSORS] = {-1.0, -1.0};           // Power
        float _energy[WSENSORS] = {-1.0, -1.0};          // Energy
        float _frequency[WSENSORS] = {-1.0, -1.0};       // Frequency
        float _co2[WSENSORS] = {-1.0, -1.0};             // CO2
        int _adc[WSENSORS] = {-1, -1};                   // Battery ADC raw data
        float _batteryVoltage[WSENSORS] = {-1.0, -1.0};  // Battery voltage
        int _batteryLevel[WSENSORS] = {-1, -1};          // Battery level
        float _batteryPercentage[WSENSORS] = {-1, -1};   // Battery percentage
};

void WirelessSensor::handleReceive() {
    while(Serial2.available()) {
        char c = Serial2.read();
        receivedData[receivedIndex] = c;
        if(receivedIndex < 1023) receivedIndex++;
    }
}

void WirelessSensor::receive() {
    String wsensorStr = "";
    char lastChar = receivedData[receivedIndex];
    char last_char = receivedData[receivedIndex - 1];
    if(lastChar == '\n' or lastChar == '}' or last_char == '\n' or last_char == '}') {
        receivedIndex = 0;
        Serial.println(SEPARATOR);
        Serial.println("Wireless sensor receive... ");

        String received = String(receivedData);
        int index = received.indexOf('\n');
        wsensorStr = received.substring(0, index);
        Serial.println(wsensorStr);
        for(uint8_t i=0; i<3; i++) {
            int startJson = wsensorStr.indexOf("{");
            int endJson = wsensorStr.indexOf("}");
            if(startJson != -1 and endJson != -1) {
                JsonDocument root;
                String js = wsensorStr.substring(startJson, endJson + 1);
                wsensorStr = wsensorStr.substring(endJson + 1);
                DeserializationError error = deserializeJson(root, js);
                if(error) {
                    Serial.println("Wireless sensor deserialization error");
                    return;
                }
                int number = root["num"];
                if(number >= 0 and number < WSENSORS) {
                    _updated[number] = now();

                    strlcpy(_sensorType[number], root["s"] | "", sizeof(_sensorType[number]));
                    strlcpy(_lightType[number], root["a"] | "", sizeof(_lightType[number]));

                    _temperature[number][0] = root["t"] | 40400.0;
                    _temperature[number][1] = root["ds"][0] | 40400.0;
                    _temperature[number][2] = root["ds"][1] | 40400.0;
                    _temperature[number][3] = root["ds"][2] | 40400.0;
                    _temperature[number][4] = root["ds"][3] | 40400.0;

                    _humidity[number] = root["h"] | 40400.0;
                    _pressure[number] = root["p"] | 40400.0;

                    _light[number] = root["l"] | -1.0;

                    _voltage[number] = root["pzem"][0] | -1.0;
                    _current[number] = root["pzem"][1] | -1.0;
                    _power[number] = root["pzem"][2] | -1.0;
                    _energy[number] = root["pzem"][3] | -1.0;
                    _frequency[number] = root["pzem"][4] | -1.0;

                    _co2[number] = root["s8"] | -1.0;

                    _adc[number] = root["b"] | -1;
                    _batteryVoltage[number] = (float)_adc[number] / (300.0 - config.wsensor_bat_k(number));
                    if(_batteryVoltage[number] > 0.0) {
                        float umin = 3.75;
                        float umax = 3.9;
                        if(config.wsensor_bat_type(number) == 0) umax = 4.5;
                        float stp = (umax - umin) / 4;
                        if(_batteryVoltage[number] < (umin + stp)) _batteryLevel[number] = 1;
                        else if(_batteryVoltage[number] < (umin + stp * 2)) _batteryLevel[number] = 2;
                        else if(_batteryVoltage[number] < (umin + stp * 3)) _batteryLevel[number] = 3;
                        else _batteryLevel[number] = 4;
                        _batteryPercentage[number] = (_batteryVoltage[number] - umin) * 100.0 / (umax - umin); 
                        if(_batteryPercentage[number] > 100.0) _batteryPercentage[number] = 100.0;
                    }

                    Serial.printf("Sensor %d updated", number);
                    if(_updated > 0)
                        Serial.printf(
                            " at: %d:%02d:%02d\r\n", 
                            hour(_updated[number]), 
                            minute(_updated[number]), 
                            second(_updated[number])
                        );
                    else Serial.println(": never");
                }
            }
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

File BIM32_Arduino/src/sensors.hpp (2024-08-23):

#include <Wire.h>
#include <Adafruit_BME280.h> // v2.2.4 https://github.com/adafruit/Adafruit_BME280_Library
#include <Adafruit_BMP085.h> // v1.2.4 https://github.com/adafruit/Adafruit-BMP085-Library
#include "SHT21.h" // https://github.com/markbeee/SHT21
#include "DHTesp.h" // v1.19.0 http://desire.giesecke.tk/index.php/2018/01/30/esp32-dht11/
#include <MAX44009.h> // v1.2.3 https://github.com/dantudose/MAX44009
#include <BH1750.h> // v1.3.0 https://github.com/claws/BH1750
#include <OneWire.h> // v2.3.7 https://github.com/PaulStoffregen/OneWire
#include <DallasTemperature.h> // v3.9.0 https://github.com/milesburton/Arduino-Temperature-Control-Library
#include "bsec.h" // v1.8.1492 https://www.bosch-sensortec.com/software-tools/software/bsec/
#include <Adafruit_PCF8574.h> // v1.1.1 https://github.com/adafruit/Adafruit_PCF8574
#include "DS3232.h" // v0.4.1 https://github.com/RobTillaart/DS3232

OneWire             oneWire(ONE_WIRE_BUS_PIN);
DallasTemperature   term(&oneWire);
DeviceAddress       thermometer;
SHT21               SHT21;
DHTesp              dht;
MAX44009            max_light;
BH1750              lightMeter(0x23);
Adafruit_BMP085     bmp;
Adafruit_BME280     bme;
Adafruit_Sensor     *bme_temp = bme.getTemperatureSensor();
Adafruit_Sensor     *bme_pressure = bme.getPressureSensor();
Adafruit_Sensor     *bme_humidity = bme.getHumiditySensor();
Adafruit_PCF8574    pcf8574;
Bsec                iaqSensor;
DS3231              rtc;

#ifdef __cplusplus
  extern "C"{
#endif
  unsigned int temprature_sens_read();
#ifdef __cplusplus
}
#endif
unsigned int temprature_sens_read();

#define DS18B20_RESOLUTION    12 /* DS18B20 resolution 9,10,11 or 12 bits */

class Sensors {
    public:
        void init(void);
        void read(void);
        void BME680Read(void);
        float get_esp32_temp(bool corr);
        float get_bme280_temp(bool corr);
        float get_bme280_hum(bool corr);
        float get_bme280_pres(bool corr);
        float get_bmp180_temp(bool corr);
        float get_bmp180_pres(bool corr);
        float get_sht21_temp(bool corr);
        float get_sht21_hum(bool corr);
        float get_dht22_temp(bool corr);
        float get_dht22_hum(bool corr);
        float get_ds18b20_temp(bool corr);
        float get_max44009_light(bool corr);
        float get_bh1750_light(bool corr);
        float get_analog_voltage(bool corr);
        float get_bme680_temp(bool corr);
        float get_bme680_hum(bool corr);
        float get_bme680_pres(bool corr);
        float get_bme680_iaq(bool corr);
        uint8_t get_bme680_iaq_accuracy();
        void get_ds3231_timeDate();
        void set_ds3231_timeDate();
        void comfortDevices(bool heater, bool cooler, bool humidifier, bool dehumidifier, bool purifier);

    private:
        bool _bme280_det = false;
        bool _bmp180_det = false;
        bool _sht21_det = false;
        bool _dht22_det = false;
        bool _ds18b20_det = false;
        bool _max44009_det = false;
        bool _bh1750_det = false;
        bool _bme680_det = false;
        bool _pcf8574_det = false;
        bool _ds3231_det = false;
        uint8_t _bme680_bsecState[BSEC_MAX_STATE_BLOB_SIZE] = {0};
        uint16_t _bme680_stateUpdateCounter = 0;
        unsigned int _bme680_stateCounter = 0;
        unsigned int _bme680_stateTimestamp = 0;

        float _esp32_temp = 40400.0;
        float _bme280_temp = 40400.0;
        float _bme280_hum = 40400.0;
        float _bme280_pres = 40400.0;
        float _bmp180_temp = 40400.0;
        float _bmp180_pres = 40400.0;
        float _sht21_temp = 40400.0;
        float _sht21_hum = 40400.0;
        float _dht22_temp = 40400.0;
        float _dht22_hum = 40400.0;
        float _ds18b20_temp = 40400.0;
        float _max44009_light = -1000.0;
        float _bh1750_light = -10000.0;
        float _analog_voltage = -10000.0;
        float _bme680_temp = 40400.0;
        float _bme680_hum = 40400.0;
        float _bme680_pres = 40400.0;
        float _bme680_iaq = 40400.0;
        uint8_t _bme680_iaq_accuracy = 0;

        void _BME280Init(void);
        void _BMP180Init(void);
        void _SHT21Init(void);
        void _DHT22Init(void);
        void _DS18B20Init(void);
        void _MAX44009Init(void);
        void _BH1750Init(void);
        void _BME680Init(void);
        void _PCF8574Init(void);
        bool _BME680_validateIaqSensorStatus(void);
        void _BME680_loadState(void);
        void _BME680_updateState(void);
        void _DS3231Init(void);

        void _BME280Read(void);
        void _BMP180Read(void);
        void _SHT21Read(void);
        void _DHT22Read(void);
        void _DS18B20Read(void);
        void _MAX44009Read(void);
        void _BH1750Read(void);
        void _AnalogRead(void);
        void _ESP32Read(void);
};

/**
 * Initialize all sensors
 */
void Sensors::init(void) {
    _DS18B20Init();
    _DHT22Init();
    _BME280Init();
    _BMP180Init();
    _SHT21Init();
    _MAX44009Init();
    _BH1750Init();
    _BME680Init();
    _PCF8574Init();
    _DS3231Init();
    Serial.println(SEPARATOR);
    Serial.println("Sensor initialization");
    Serial.printf("%s %s%s\r\n", "DS18B20:  ", _ds18b20_det ? "" : "NOT ", "Detected");
    Serial.printf("%s %s%s\r\n", "BME280:   ", _bme280_det ? "" : "NOT ", "Detected");
    Serial.printf("%s %s%s\r\n", "BMP180:   ", _bmp180_det ? "" : "NOT ", "Detected");
    Serial.printf("%s %s%s\r\n", "SHT21:    ", _sht21_det ? "" : "NOT ", "Detected");
    Serial.printf("%s %s%s\r\n", "DHT22:    ", _dht22_det ? "" : "NOT ", "Detected");
    Serial.printf("%s %s%s\r\n", "MAX44009: ", _max44009_det ? "" : "NOT ", "Detected");
    Serial.printf("%s %s%s\r\n", "BH1750:   ", _bh1750_det ? "" : "NOT ", "Detected");
    Serial.printf("%s %s%s\r\n", "BME680:   ", _bme680_det ? "" : "NOT ", "Detected");
    Serial.printf("%s %s%s\r\n", "PCF8574:  ", _pcf8574_det ? "" : "NOT ", "Detected");
    Serial.printf("%s %s%s\r\n", "DS3231:   ", _ds3231_det ? "" : "NOT ", "Detected");
}

/**
 * Reads all sensors
 */
void Sensors::read(void) {
    _BME280Read();
    _BMP180Read();
    _SHT21Read();
    _DHT22Read();
    _DS18B20Read();
    _MAX44009Read();
    _BH1750Read();
    _ESP32Read();
    _AnalogRead();
}

/**
 * Getters
 */
float Sensors::get_esp32_temp(bool corr) {
    return _esp32_temp + (corr ? config.esp32_temp_corr() : 0.0);
}

float Sensors::get_bme280_temp(bool corr) {
    return _bme280_temp + (corr ? config.bme280_temp_corr() : 0.0);
}

float Sensors::get_bme280_hum(bool corr) {
    return _bme280_hum + (corr ? config.bme280_hum_corr() : 0.0);
}

float Sensors::get_bme280_pres(bool corr) {
    return _bme280_pres + (corr ? config.bme280_pres_corr() : 0.0);
}

float Sensors::get_bmp180_temp(bool corr) {
    return _bmp180_temp + (corr ? config.bmp180_temp_corr() : 0.0);
}

float Sensors::get_bmp180_pres(bool corr) {
    return _bmp180_pres + (corr ? config.bmp180_pres_corr() : 0.0);
}
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

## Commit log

2021-10-31 bug fix of daylight saving time, display off added
    [web.ino]
2021-11-21 pcb from Maxim1960
2021-12-27 PCB from mikolasnn
2022-12-24 weather forecast bug fixed
    [globals.hpp, weather.hpp]
2022-12-24 added 3d models
    [Crystal_SMD_3P_3213.step, GY-BME280.SLDPRT]
2022-12-27 fixed hang bug when getting forecast
    [weather.hpp]
2022-12-27 fixed battery voltage display
    [wirelessSensor.hpp]
2022-12-28 fix reading config file
    [globals.hpp]
2023-01-04 added battery percentage
2023-01-09 fixed the stability of HC-12
    [globals.hpp, wirelessSensor.hpp]
2023-03-03 runtime display-bug fix (thenks VR70)
    [web.ino]
2023-03-03 self-reboot fix [memory overflow] (thanks VR70)
    [weather.hpp]
2023-08-04 changed pressure range
2023-08-04 added smd elements parallel to through-hole
2023-12-06 add Senseair S8 CO2 sensor
2023-12-31 add BME680 and SenseAir S8 sensors
2024-01-01 add BME680 sensor enclosure
    [BME680_assembly.SLDASM, BME680_cover.SLDPRT, BME680_cover.STL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]
2024-01-01 add SenseAir S8 sensor
2024-01-01 add BME680 sensor
2024-01-03 replace streaming weather parser library
    [globals.hpp, weather.hpp]
2024-01-05 update link to Radio-sensor
2024-01-08 do not save bme680 status if file is missing
    [sensors.hpp]
2024-01-11 fix alarm button pin
2024-01-11 battery percentage is float
2024-02-04 move wireless sensor to its own repository
2024-06-18 removed unnecessary files
    [2d_bridge.SLDPRT, 3d_bridge.SLDPRT, 4d_bridge.SLDPRT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]
2024-06-18 renamed folders
    [BME680_assembly.SLDASM, BME680_cover.SLDPRT, BME680_main.SLDPRT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]
2024-06-21 update develop schematics
2024-06-22 changed the way sensors are corrected
    [globals.hpp, ili9341.hpp, sensors.hpp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]
2024-06-24 added arduino-cli output directoty to gitignore
2024-07-28 ds18b20 & dht22 on sda scl wires
2024-07-28 switchable transmission/reception
2024-07-31 sensors pins
2024-08-01 added touch_cs pin
2024-08-02 fixed the formation of file list
    [web.ino]
2024-08-02 fixed the impossibility of disabling data sending
    [globals.hpp]
2024-08-02 reworking sound and alarm
    [globals.hpp]
2024-08-04 fixed sensor readings not being displayed
2024-08-07 removed irrelevant case
    [11_20mm pin.sldprt, 1mm.sldprt, 1x4_Male_Pin_Header_Angle.sldprt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]
2024-08-07 new schematic diagram
2024-08-08 pcb v4.0
    [1x4 Male Pin Header Angle.STEP, 3.5_Jack.STEP, BH-642_Battery_holder.STEP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]
2024-08-08 3d model of pcb
2024-08-09 rename folder
    [BME680_assembly.SLDASM, BME680_cover.SLDPRT, BME680_cover.STL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]
2024-08-11 fix battery level from thingspeak
    [agregateData.hpp]
2024-08-11 bug fix - display temp and hum from BME680
    [globals.hpp]
2024-08-11 compatibility with old wireless sensor
2024-08-11 improved stability of bme680 sensor
    [sensors.hpp]
2024-08-11 schematic v4.0
2024-08-14 fixed color management from web interface
    [web.ino]
2024-08-18 3D printing device housing
    [board.SLDPRT, btnExt.SLDPRT, btnReset.SLDPRT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]
2024-08-21 fixed the air quality color
    [agregateData.hpp]
2024-08-21 fixed missing weather description
    [ili9341.hpp]
2024-08-23 Improved stability of radio sensor reception
    [BIM32_Arduino.ino, wirelessSensor.hpp]
2024-08-30 fix ws2812 color change from web page
    [web.ino]
2024-08-30 Fixing broken display on/off button
    [BIM32_Arduino.ino, globals.hpp]
2024-09-08 changed method of communication with DFPlayer
    [1 - Top.gbr, 2 - Bottom.gbr, BoardOutline.gbr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]
2024-09-24 switched from asynchronous to synchronous web server
2024-10-04 broke the deserialization of the hourly forecast into sections
    [weather.hpp]
2024-10-05 added clock pages to touch switch
2024-10-06 added calendar page to touch switch
2024-10-08 added network page to touch switch
2024-10-09 added hourly forecast page to touch switch
2024-10-10 added history pages to touch switch
2024-10-11 added alarm page to touch switch
2024-10-15 Eliminate simultaneous access to the I2C bus from different tasks
2024-10-17 fix slot change animations for WS2812b display
    [BIM32_Arduino.ino, globals.hpp, segmentDisplay.hpp]
2024-10-31 added high voltage displaying from thingspeak
2024-11-23 fixed "comfortable" not showing
    [BIM32_Arduino.ino, globals.hpp]
2024-11-23 cropping text that doesn't fit & co2 width correction
    [ili9341.hpp]
2024-12-08 PWM adjustment of the numitron display brightness & tubes backlight
2024-12-08 pcb rev.A01
2024-12-15 corrected the schematic-pictures
2024-12-22 alignment of some tracks on PCB
    [1 - Top.gbr, 2 - Bottom.gbr, BoardOutline.gbr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]
2025-01-03 correction of current weather data
    [agregateLcdData.hpp, agregateSegmentData.hpp, agregateSendData.hpp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]
2025-01-06 added clock formats & current weather correction
2025-01-14 Touchscreen calibration is enabled in web interface
2025-01-14 a hole for mounting the photoresistor
    [1 - Top.gbr, 2 - Bottom.gbr, BottomMask.gbr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]
2025-01-15 fix clock format of main screen
    [BIM32_Arduino.ino, globals.hpp, ili9341.hpp]
2025-01-19 moving numitron display to software i2c
2025-01-19 shift HC-12 and speaker connector to the bottom side
    [JST - XH - Thru (R) - 2Pin - 2.54mm.stp, JST - XH - Thru (V) - 4Pin - 2.54mm.stp, JST 2pin.stp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]
2025-01-19 updated enclosure
    [alarm_black.SLDPRT, alarm_white.SLDPRT, board.SLDPRT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]
